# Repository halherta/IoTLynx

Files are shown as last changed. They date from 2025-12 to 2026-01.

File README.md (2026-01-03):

# IoTLynx

A maker-friendly ESP32-C6 development board designed for accessibility and ease of use.

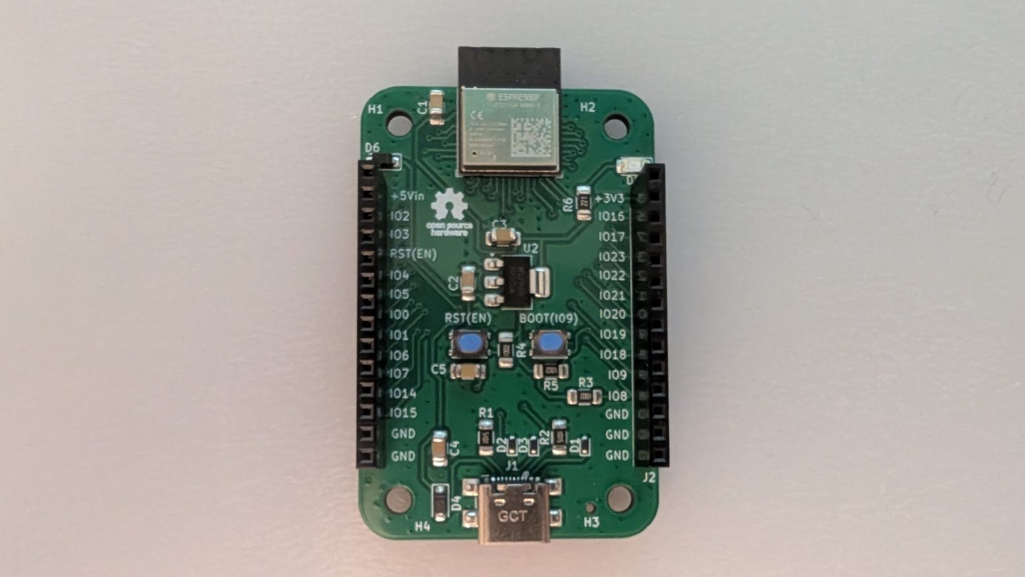
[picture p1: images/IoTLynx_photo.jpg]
IoTLynx Board


## Overview

IoTLynx is a microcontroller development board based on Espressif's ESP32-C6 microcontroller (ESP32-C6-MINI-1 module). Designed with accessibility in mind, the IoTLynx platform caters to makers, hobbyists, and newcomers to programming and electronics. Though the board supports C programming, it was specifically designed to run MicroPython—a choice that aligns with its philosophy of ease of use. With the MicroPython REPL pre-loaded and ready to run, users can start coding immediately without the hassle of configuring development environments or installing IDEs.

## Features

### Hardware Specifications

**ESP32-C6 (ESP32-C6-MINI-1) Module:**
- **Processor:** RISC-V 32-bit single-core, up to 160 MHz
- **Memory:** 512 KB SRAM, 320 KB ROM, 4 MB embedded flash
- **Wireless:** Wi-Fi 6 (802.11 b/g/n, 2.4 GHz), Bluetooth 5.3 LE
- **GPIO:** 19 programmable GPIOs available on headers
- **Interfaces:** 2× SPI, 2× UART, 1× I2C, 1× I2S
- **Analog:** 7-channel 12-bit SAR ADC
- **PWM:** 6 LED PWM channels
- **USB:** USB 2.0 full-speed (OTG)
- **Other:** Built-in temperature sensor, 7-channel capacitive touch, hardware encryption

**Board Features:**
- **Dimensions:** 58mm × 38mm with rounded edges
- **Power Options:** USB-C or +5V via pin (can use both simultaneously)
- **Voltage Regulator:** Onboard +3.3V regulator
- **Headers:** 2× 14-pin female headers for GPIO access
- **Buttons:** RESET and BOOT pushbuttons
- **LED:** Power-on indicator
- **PCB:** 2-layer design with ground fills for noise immunity
- **Mounting:** M3 mounting holes on all four corners

### Power Consumption
- **Active mode (Wi-Fi):** ~95 mA
- **Modem-sleep:** ~15 mA
- **Light-sleep:** ~3 mA
- **Deep-sleep:** ~7-10 µA

## Pinout

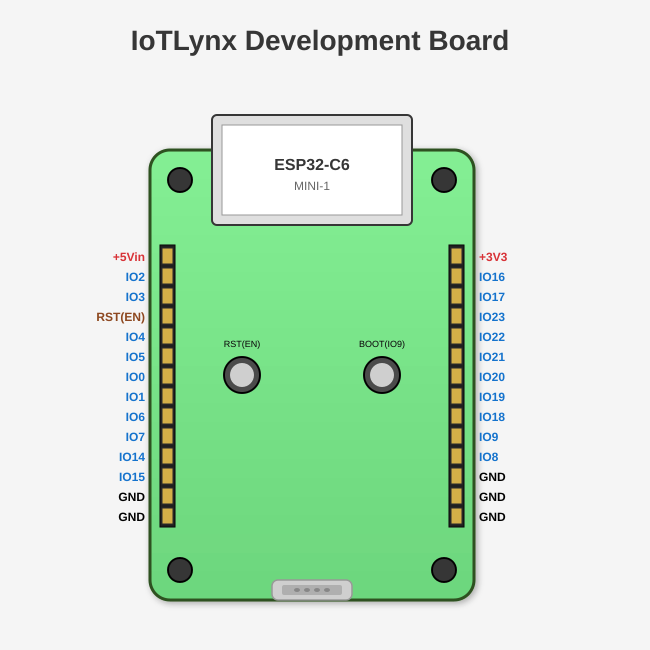
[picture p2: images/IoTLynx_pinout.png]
IoTLynx Pinout


Power can be applied via:
- **USB-C connector** for programming and power
- **+5Vin pin** (5V only) - can be used simultaneously with USB-C
- **+3V3 output** available for powering external components

## Schematic & PCB

The board features a straightforward design with all ESP32-C6-MINI-1 GPIOs (except USB pins) brought out to the headers. View the [full schematic PDF](https://github.com/halherta/IoTLynx/blob/main/IoTLynx.pdf) for complete details.

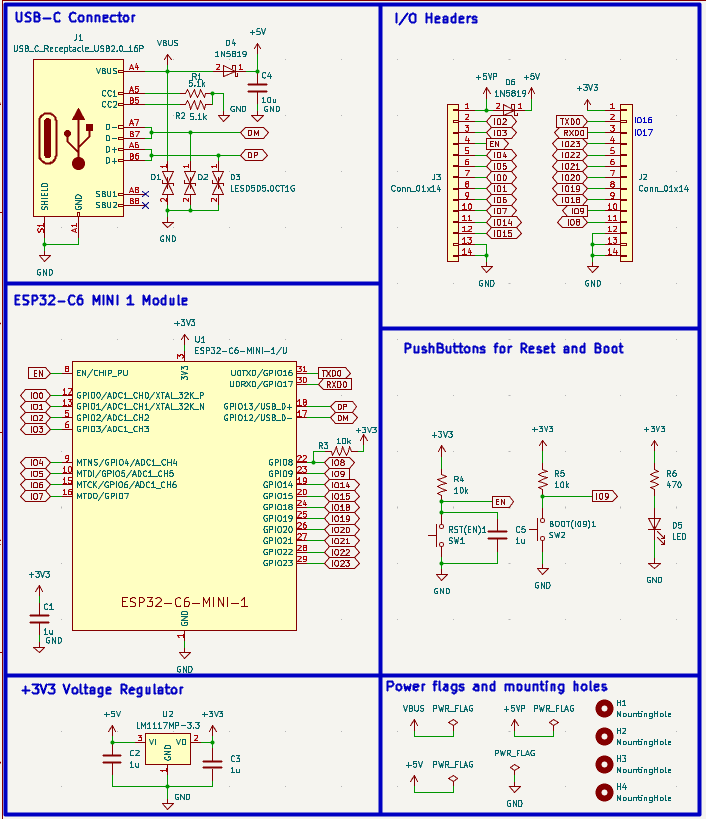
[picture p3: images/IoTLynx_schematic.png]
IoTLynx Schematic

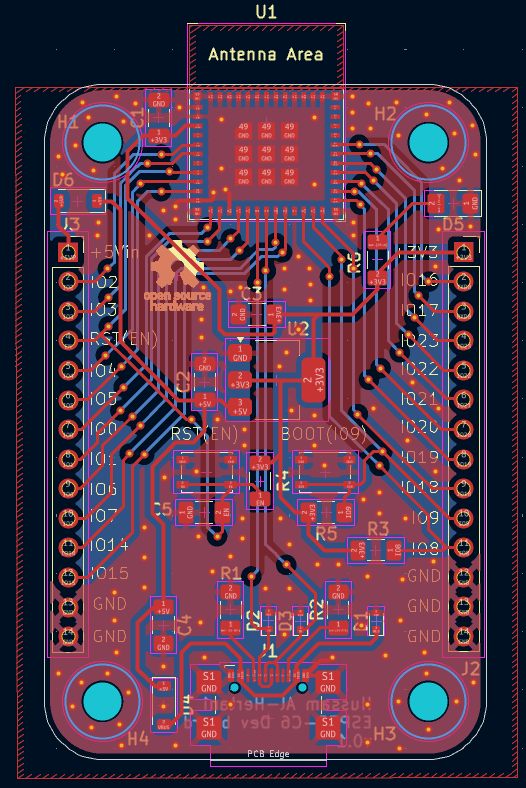
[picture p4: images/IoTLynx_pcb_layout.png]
IoTLynx PCB Layout

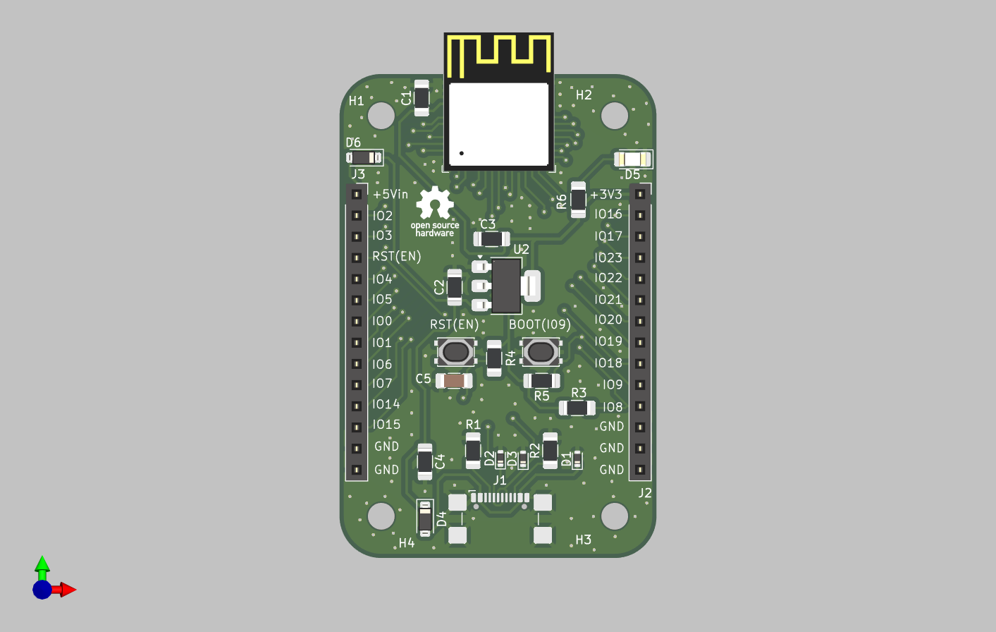
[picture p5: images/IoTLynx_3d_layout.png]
IoTLynx 3D Render


## Expansion Boards

The IoTLynx is designed to support "Top" boards—add-on boards that attach via the two female header connectors, similar to Arduino shields or Raspberry Pi hats. A KiCad template for creating Top boards is available in the [parts library](https://github.com/halherta/mykicadlibrary).

## Getting Started

### Prerequisites

- [Thonny IDE](https://thonny.org/) (MicroPython IDE)
- [esptool](https://github.com/espressif/esptool) (Espressif's flashing tool)
- [MicroPython firmware for ESP32-C6](https://micropython.org/download/ESP32_GENERIC_C6/)

### Installation

**1. Install Thonny and esptool:**

Via pip (in a Python virtual environment):
```bash
pip install thonny esptool
```

Or via apt (Debian/Ubuntu):
```bash
sudo apt install thonny esptool
```

**2. Find your serial port:**

Linux/Mac:
```bash
ls /dev/tty*
```

Windows (PowerShell):
```powershell
[System.IO.Ports.SerialPort]::getportnames()
```

Look for something like `/dev/ttyUSB0`, `/dev/ttyACM0` (Linux/Mac) or `COM3`, `COM4` (Windows).

**3. Erase the flash:**
```bash
esptool --chip esp32c6 --port /dev/ttyUSB0 erase_flash
```
*Replace `/dev/ttyUSB0` with your actual serial port.*

**4. Flash MicroPython firmware:**
```bash
esptool --chip esp32c6 --port /dev/ttyUSB0 write_flash -z 0x0 ESP32_GENERIC_C6-XXXXXXXX.bin
```
*Replace `ESP32_GENERIC_C6-XXXXXXXX.bin` with your downloaded firmware filename.*

**5. Configure Thonny:**
- Open Thonny
- Go to **Run → Configure Interpreter**
- Select **MicroPython (ESP32)** from the first dropdown
- Select your board's serial port from the second dropdown
- Click **OK**

You should see the MicroPython REPL prompt in the shell window:
```python
MicroPython v1.xx.x on 20xx-xx-xx; ESP32C6 module with ESP32C6
Type "help()" for more information.
>>>
```

Congratulations! You're ready to program your IoTLynx board!

## Repository Contents

- **IoTLynx.kicad_\*** - KiCad project files (schematic, PCB, settings)
- **IoTLynx.pdf** - Schematic in PDF format
- **IoTLynx.svg** - Board illustration
- **production/** - Manufacturing files (gerbers, BOM, etc.)
- **images/** - Documentation images
- **\*-backups/** - KiCad backup files

## Resources

- **Blog Post:** [Detailed IoTLynx writeup](https://hussamtalkstech.com/iotlynx/)
- **Parts Library:** [KiCad parts and Top board template](https://github.com/halherta/mykicadlibrary)
- **ESP32-C6 Datasheet:** [ESP32-C6-MINI-1 documentation](https://documentation.espressif.com/esp32-c6-mini-1_mini-1u_datasheet_en.html)
- **MicroPython Documentation:** [MicroPython for ESP32](https://docs.micropython.org/en/latest/esp32/quickref.html)

## License

This hardware project is open source. Please check the repository for specific license information.

## Contributing

Contributions, issues, and feature requests are welcome! Feel free to check the issues page or submit a pull request.

## Support

For questions, issues, or discussions about the IoTLynx board:
- Open an issue on this repository
- Visit the [blog post](https://hussamtalkstech.com/iotlynx/) for additional details

## Author

Created by [halherta](https://github.com/halherta)

---

**Note:** While the ESP32-C6 supports Zigbee, Thread, 6LoWPAN, and Matter protocols, these features are not currently available through MicroPython.

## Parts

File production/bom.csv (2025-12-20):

Designator | Footprint | Quantity | Value | LCSC Part #
BOOT(I09) | SW_SPST_PTS810 | 1 | SW2
C1, C2, C3, C5 | 1206 | 4 | 1u
C4 | 1206 | 1 | 10u
D1, D2, D3 | D_SOD-523 | 3 | LESD5D5.0CT1G
D4, D6 | D_SOD-123 | 2 | 1N5819
D5 | 1206 | 1 | LED
J1 | USB_C_Receptacle_GCT_USB4110 | 1 | USB_C_Receptacle_USB2.0_16P
J2, J3 | PinSocket_1x14_P2.54mm_Vertical | 2 | Conn_01x14
R1, R2 | 1206 | 2 | 5.1k
R3, R4, R5 | 1206 | 3 | 10k
R6 | 1206 | 1 | 220
RST(EN) | SW_SPST_PTS810 | 1 | SW1
U1 | ESP32-C6-MINI-1 | 1 | ESP32-C6-MINI-1/U
U2 | SOT-223-3_TabPin2 | 1 | LM1117MP-3.3

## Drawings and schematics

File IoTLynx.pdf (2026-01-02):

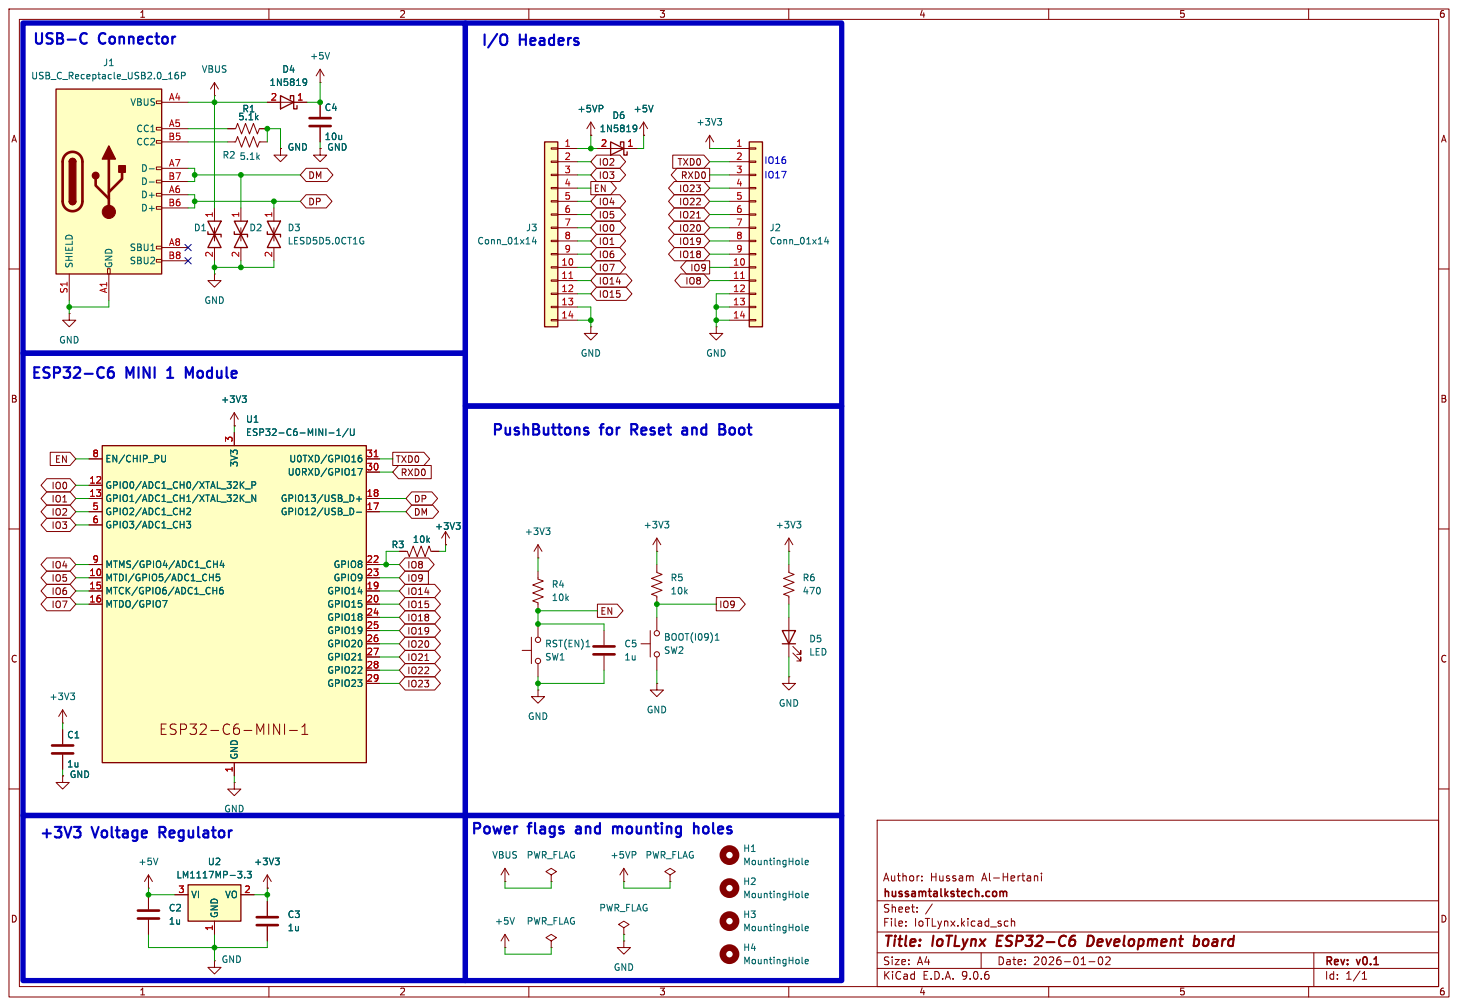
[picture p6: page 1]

Power flags and mounting holes

File: IoTLynx.kicad_sch Sheet: / hussamtalkstech.com

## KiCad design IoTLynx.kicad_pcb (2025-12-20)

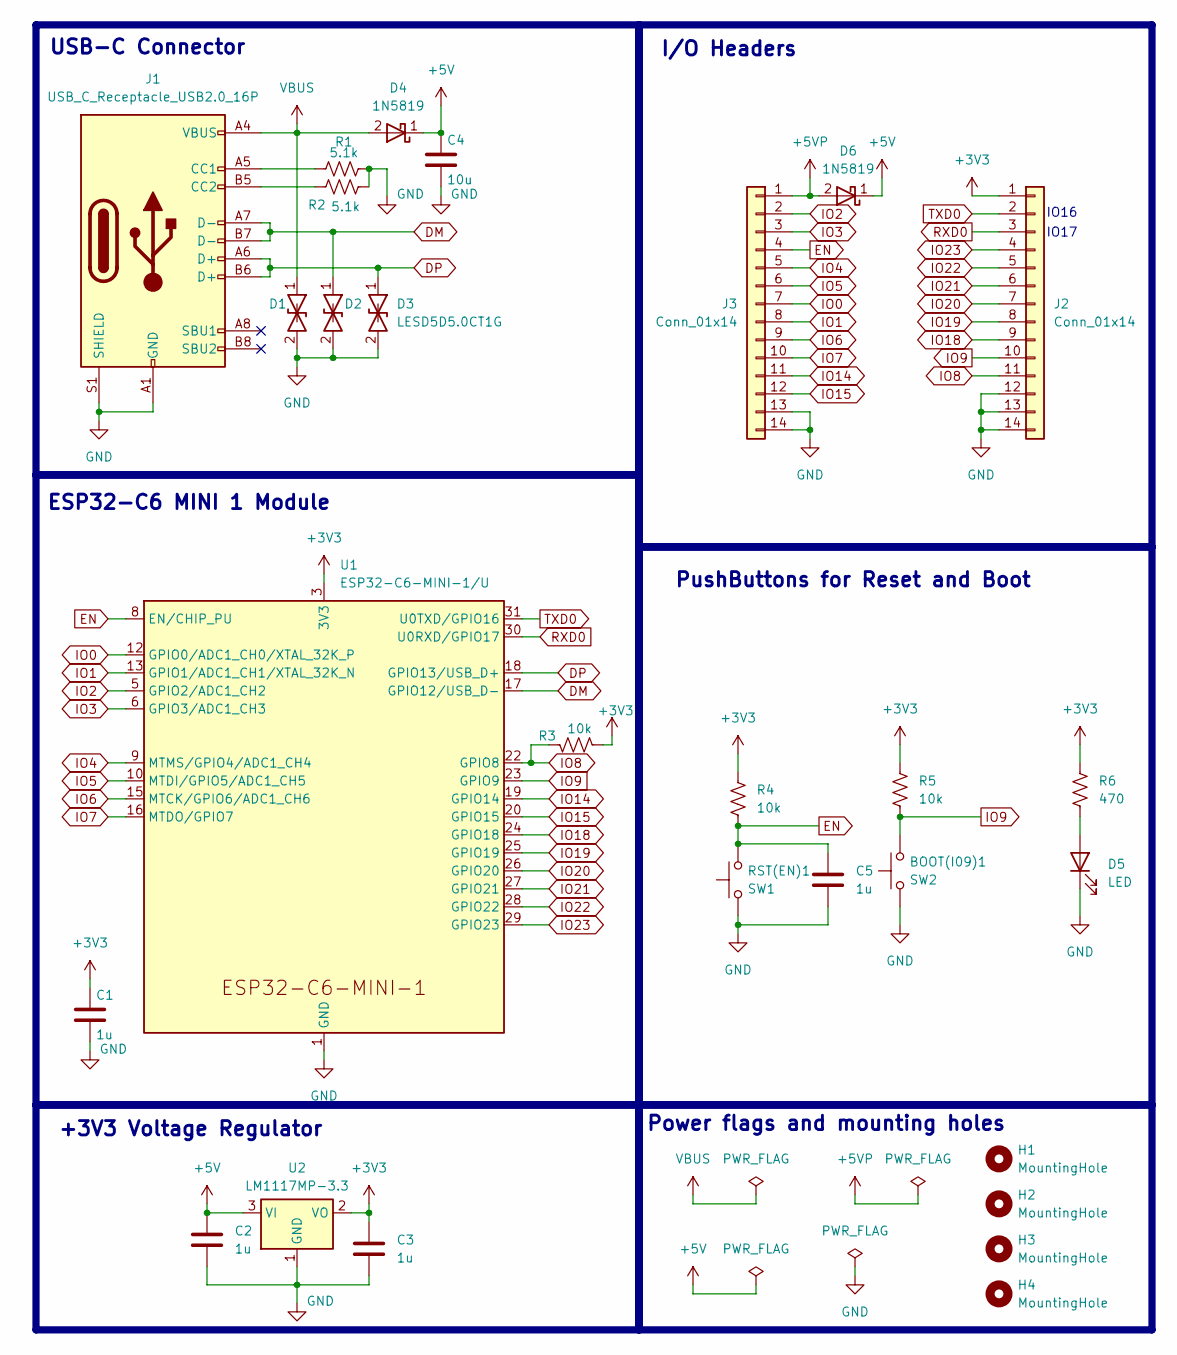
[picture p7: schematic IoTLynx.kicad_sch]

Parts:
BOOT(I09)1: SW2; SW_SPST_PTS810
C1, C2, C3: 1u; R_1206_3216Metric_Pad1.30x1.75mm_HandSolder
C4: 10u; R_1206_3216Metric_Pad1.30x1.75mm_HandSolder
C5: 1u; C_1206_3216Metric_Pad1.33x1.80mm_HandSolder
D1, D2, D3: LESD5D5.0CT1G; D_SOD-523
D4, D6: 1N5819; D_SOD-123
D5: LED; LED_1206_3216Metric_Pad1.42x1.75mm_HandSolder
H1, H2, H3, H4: MountingHole; MountingHole_3.2mm_M3
J1: USB_C_Receptacle_USB2.0_16P; USB_C_Receptacle_GCT_USB4110
J2, J3: Conn_01x14; PinSocket_1x14_P2.54mm_Vertical
R1, R2: 5.1k; R_1206_3216Metric_Pad1.30x1.75mm_HandSolder
R3, R4, R5: 10k; R_1206_3216Metric_Pad1.30x1.75mm_HandSolder
R6: 470; R_1206_3216Metric_Pad1.30x1.75mm_HandSolder
RST(EN)1: SW1; SW_SPST_PTS810
U1: ESP32-C6-MINI-1/U; ESP32-C6-MINI-1
U2: LM1117MP-3.3; SOT-223-3_TabPin2

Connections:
+3V3: C1.1, C3.1, J2.1, R3.2, R4.2, R5.2, R6.2, U1.3 (3V3), U2.2 (VO)
+5V: C2.1, C4.1, D4.1 (K), D6.1 (K), U2.3 (VI)
+5VP: D6.2 (A), J3.1
DM: D2.1 (A1), J1.A7 (D-), J1.B7 (D-), U1.17 (GPIO12/USB_D-)
DP: D3.1 (A1), J1.A6 (D+), J1.B6 (D+), U1.18 (GPIO13/USB_D+)
EN: C5.2, J3.4, R4.1, RST(EN)1.2, U1.8 (EN/CHIP_PU); also elsewhere on the board
GND: BOOT(I09)1.1, C1.2, C2.2, C3.2, C4.2, C5.1, D1.2 (A2), D2.2 (A2), D3.2 (A2), D5.1 (K), J1.A1 (GND), J1.A12 (GND), J1.B1 (GND), J1.B12 (GND), J1.S1 (SHIELD), J2.12, J2.13, J2.14, J3.13, J3.14, R1.2, R2.2, RST(EN)1.1, U1.1 (GND), U1.2 (GND), U1.11 (GND), U1.14 (GND), U1.36 (GND), U1.37 (GND), U1.38 (GND), U1.39 (GND), U1.40 (GND), U1.41 (GND), U1.42 (GND), U1.43 (GND), U1.44 (GND), U1.45 (GND), U1.46 (GND), U1.47 (GND), U1.48 (GND), U1.49 (GND), U1.50 (GND), U1.51 (GND), U1.52 (GND), U1.53 (GND), U2.1 (GND); also elsewhere on the board
IO0: J3.7, U1.12 (GPIO0/ADC1_CH0/XTAL_32K_P)
IO1: J3.8, U1.13 (GPIO1/ADC1_CH1/XTAL_32K_N)
IO2: J3.2, U1.5 (GPIO2/ADC1_CH2)
IO3: J3.3, U1.6 (GPIO3/ADC1_CH3)
IO4: J3.5, U1.9 (MTMS/GPIO4/ADC1_CH4)
IO5: J3.6, U1.10 (MTDI/GPIO5/ADC1_CH5)
IO6: J3.9, U1.15 (MTCK/GPIO6/ADC1_CH6)
IO7: J3.10, U1.16 (MTDO/GPIO7)
IO8: J2.11, R3.1, U1.22 (GPIO8)
IO9: BOOT(I09)1.2, J2.10, R5.1, U1.23 (GPIO9); also elsewhere on the board
IO14: J3.11, U1.19 (GPIO14)
IO15: J3.12, U1.20 (GPIO15)
IO18: J2.9, U1.24 (GPIO18)
IO19: J2.8, U1.25 (GPIO19)
IO20: J2.7, U1.26 (GPIO20)
IO21: J2.6, U1.27 (GPIO21)
IO22: J2.5, U1.28 (GPIO22)
IO23: J2.4, U1.29 (GPIO23)
unnamed: D5.2 (A), R6.1
unnamed: J1.A5 (CC1), R1.1
unnamed: J1.B5 (CC2), R2.1
RXD0: J2.3, U1.30 (U0RXD/GPIO17)
TXD0: J2.2, U1.31 (U0TXD/GPIO16)
VBUS: D1.1 (A1), D4.2 (A), J1.A4 (VBUS), J1.A9 (VBUS), J1.B4 (VBUS), J1.B9 (VBUS)

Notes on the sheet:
USB-C Connector
+3V3 Voltage Regulator
PushButtons for Reset and Boot
I/O Headers
Power flags and mounting holes
ESP32-C6 MINI 1 Module
IO17
IO16

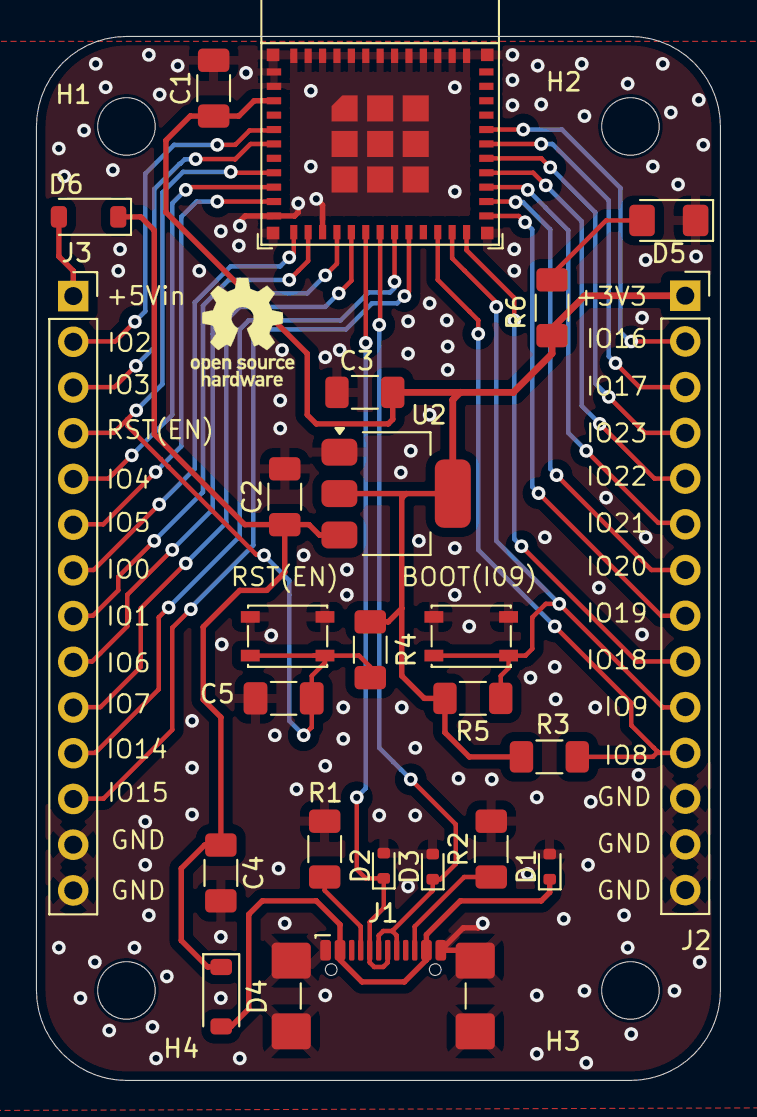
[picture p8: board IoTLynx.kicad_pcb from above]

Board: 2 copper layers, 38.0 x 58.0 mm, 28 parts (0 on the bottom side), 31 nets.

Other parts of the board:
BOOT(I09): SW2; SW_SPST_PTS810
RST(EN): SW1; SW_SPST_PTS810

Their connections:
EN: RST(EN).2; also elsewhere on the board
GND: BOOT(I09).1, RST(EN).1; also elsewhere on the board
IO9: BOOT(I09).2; also elsewhere on the board
